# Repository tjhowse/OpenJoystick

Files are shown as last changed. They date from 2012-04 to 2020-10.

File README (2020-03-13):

OpenJoystick

OpenJoystick is a project developing a 3D-printable joystick and throttle for use with flight simulators. The design is centered around making the joystick cheap, easy to assemble and simple to customise. Where-ever possible, commonly available and inexpensive components are used where 3D printed parts would be unsuitable, such as switches, bearings and sensors. The designs of the components are parametric. This means they can be simply modified in a text editor in order to create customised joysticks for different aircraft, left-handed people, or people with limited mobility. The deflection of the joystick is measured using a tri-axis hall effect sensor. This yields great accuracy, reliability and long life, due to non-contact sensing. The 3D models and circuitry used in OpenJoystick are open source under the Gnu Public License. Anyone can visit openjoystick.org download the source code and start hacking.

http://www.youtube.com/watch?v=GIY6-3KwIS8&feature=bf_prev&list=PLC66292176B625E2A&lf=plpp_video

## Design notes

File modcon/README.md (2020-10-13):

# Modular Control Panel

This is a project to create a modular control panel for controlling flight simulators and
games on a computer.

Each module contains a microcontroller that interfaces to the inputs on that module and can
relay the states of those inputs to an adjacent module. A module can be fitted with a USB
port to interface to a PC via a standard HID joystick interface. The input devices can be
joysticks, buttons, switches, sliders, knobs or anything else that can be connected to an
arduino-style microcontroller.

https://www.youtube.com/watch?v=Ra9WzwZtf44

The goal is to enable non- or semi-technical people to build custom computer peripherals
to suit how they want to interact with their favourite game or simulator. The PC interface
is via standard USB HID joystick device, so should work with a wide range of software and
platforms (Windows, OSX, Linux, consoles...?).

## This sounds great! I want one!

This project aims to produce the CAD files, circuit board designs and firmware to support
people building their own modular control panels. Further down the road there may be a
small-scale store selling kits, but that's a fair way away.

This is definitely a do-it-yourself kind of project. It might seem like this would
be impossible for a beginner to build, but it may be simpler than you imagine. Learning
a few new skills and building something that is unique to you can feel very rewarding.
Don't be intimidated!

The main things you'll need are:

### The boxes/lids

These are 3d printed. If you don't have a 3d printer of your own there are online services
that you use to print and ship components to you. Alternatively ask a friend with a 3d
printer, or visit your local makerspace/hackerspace/library. They're more common than you
might think.

### The PCBs

The Printed Circuit Board (PCB) is designed such that it can be ordered from JLC PCB
inexpensively and arrive in a nearly-ready-to-use form. Any components that JLC can't
populate on the board are easy to solder by hand.

### Input devices

Switches, buttons, joysticks, et cetera. These are readily available from your online
retailer of choice. The bill of materials (BoM) will provide model numbers and links
for where you could buy them.

### Soldering iron and solder

A cheap electrical soldering iron and some flux-core solder is all you will need. Don't
be scared! It's not as hard as you might think.

### Bits and bobs

The bill of materials (BoM) will list some inexpensive wires, plugs and header strips
you'll need to assemble your controller modules.

## Fabrication notes

### Drilling large holes in the lid

If you need to drill a 40mm hole to mount a three-axis joystick module, like [this one](https://www.aliexpress.com/item/32808586573.html)
be very careful not to overshoot and break the part. I used a 45mm holesaw and snapped the lid in half
as I broke through the other side. If possible I suggest printing the lid with the hole already in place,
or being very careful when drilling.

## FAQ

### I would like outputs like displays and lights too!

That would be be neat. However I'm not aware of a standard way of getting that information
out of a simulator. There are plenty of examples of custom integrations with specific software,
but I'm not aware of any equivalent to a USB HID joystick input, but for outputs in terms of
near-universal support.

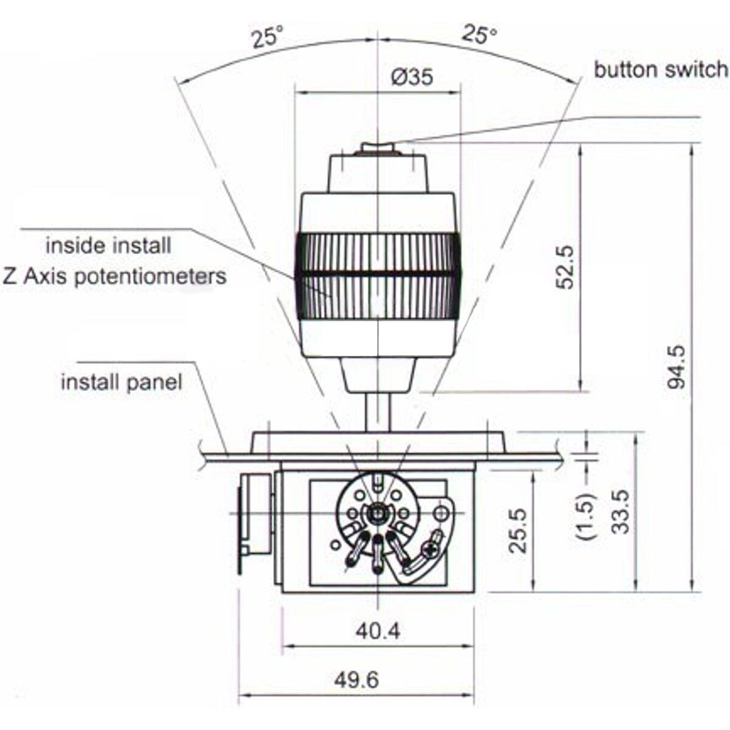
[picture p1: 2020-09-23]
modcon/images/joystick_module_dimensions.jpg

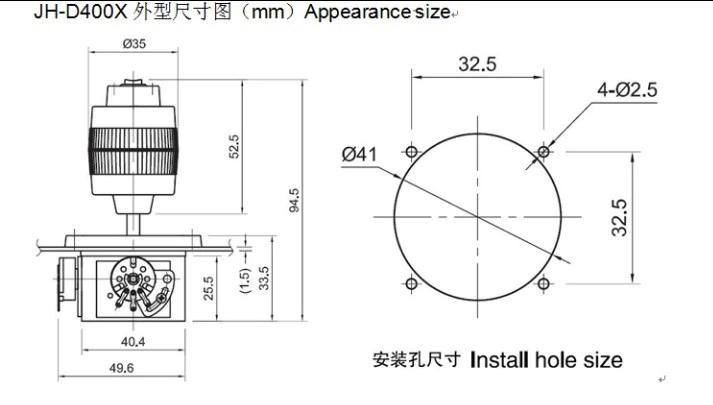
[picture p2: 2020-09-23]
modcon/images/HTB1k1w9kmYH8KJjSspdq6ARgVXaa.webp

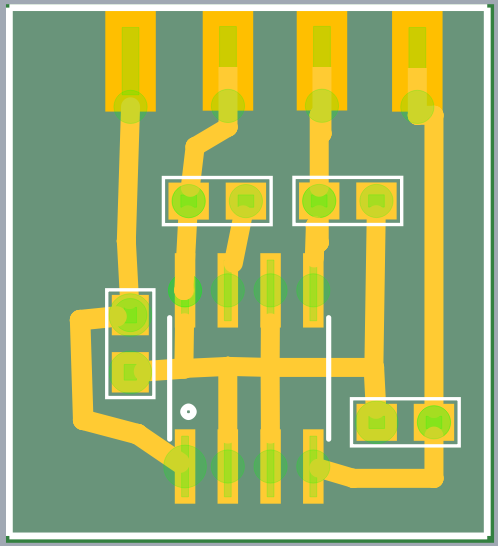
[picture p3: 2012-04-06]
pcb/hall.png

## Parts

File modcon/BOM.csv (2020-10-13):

description | partno | url
Joystick | HW0000997 | https://www.aliexpress.com/item/32808586573.html

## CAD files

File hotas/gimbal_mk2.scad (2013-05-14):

/*
	OpenJoystick - A project creating affordable, open source, 3D-printable custom flight-sim joysticks for everyone
	Copyright (C) 2012 Travis John Howse

	This program is free software: you can redistribute it and/or modify
	it under the terms of the GNU General Public License as published by
	the Free Software Foundation, either version 3 of the License, or
	(at your option) any later version.

	This program is distributed in the hope that it will be useful,
	but WITHOUT ANY WARRANTY; without even the implied warranty of
	MERCHANTABILITY or FITNESS FOR A PARTICULAR PURPOSE.  See the
	GNU General Public License for more details.

	You should have received a copy of the GNU General Public License
	along with this program.  If not, see <http://www.gnu.org/licenses/>.
*/

include <joystick_defines.scad>
use <joystick_handle.scad>

wall_thickness = 2;
m8_bolt_clearance = 1.1;
m8_bolt_head_z = 6.25*m8_bolt_clearance;
m8_bolt_head_min_r = 12.74/2*m8_bolt_clearance;
m8_bolt_head_max_r = 14.55/2*m8_bolt_clearance;

// These come from experimentally-discovered determined values for good springyness
// using 1.5mm spring steel piano wire.
outer_spring_pegs = 50; // Try increasing this.
inner_spring_pegs = 10;

spring_peg_r = 1.5;

bearing_outside_dia = 22*1.02;

y_clearance = 3; // Two washers' worth
anchor_clearance = 3;
z_clearance = 2;
z_extra_bolt_clearance = 1;

y_extra_sleeve_clearance = 2;

y_pegs_offset = bearing_inside_dia/2 + (bearing_inside_dia/2+bearing_inside_dia/2)/2-spring_peg_r;

//spring_z_offset = 2;
spring_z_offset = 2*spring_peg_r;
//spring_z_offset = 0;
spring_peg_sleeve_y = y_pegs_offset-spring_peg_r-(spring_z_offset-2*spring_peg_r);
spring_peg_sleeve_x = y_pegs_offset-spring_peg_r-(spring_z_offset-2*spring_peg_r);

spring_wire_r = 1.5/2;

y_total_z = bearing_thickness*2;	
// y_total_y = outer_spring_pegs+spring_peg_sleeve_y*2+spring_wire_r*2+y_extra_sleeve_clearance;
y_total_y = outer_spring_pegs+spring_peg_sleeve_y*2+y_extra_sleeve_clearance;
y_total_x = (m8_bolt_head_min_r+wall_thickness)*2;

magnet_d = 10*1.1;
magnet_z = 5;

anchor_base_thickness = 2*wall_thickness;
anchor_base_extra_height = 15;
anchor_total_z = bearing_thickness*2;

stem_socket_depth = 10;

module m8_bolt(length,slothead,slotshaft)
{
	rotate([0,0,90]) union()
	{
		translate([0,0,zff]) cylinder(r=m8_bolt_head_max_r,h=m8_bolt_head_z,$fn=6);
		translate([0,0,m8_bolt_head_z]) cylinder(r=bearing_inside_dia/2,h=length);
		if (slothead == 1)
		{
			translate([0,-m8_bolt_head_min_r,0]) cube([m8_bolt_head_min_r*2,m8_bolt_head_min_r*2,m8_bolt_head_z]);
			// translate([0,-bearing_inside_dia/2,m8_bolt_head_z]) cube([m8_bolt_head_min_r*2,bearing_inside_dia,length]);
		}
		if (slotshaft == 1)
		{
			// translate([0,-m8_bolt_head_min_r,0]) cube([m8_bolt_head_min_r*2,m8_bolt_head_min_r*2,m8_bolt_head_z]);
			translate([0,-bearing_inside_dia/2,m8_bolt_head_z]) cube([m8_bolt_head_min_r*2,bearing_inside_dia,length]);
		}
		
	}
}

module y_axis()
{	
	edge_chord = 2*sqrt(pow((bearing_outside_dia+wall_thickness*2)/2,2)-pow(y_total_x/2,2));
	
	difference()
	{
		union()
		{
			bearing_clamp();
			cube([y_total_x,y_total_y,y_total_z],true);
			/*translate([y_pegs_offset,-outer_spring_pegs/2,-y_total_z/2]) cylinder(r=spring_peg_r+wall_thickness,h=y_total_z);
			rotate([0,0,180]) translate([-y_pegs_offset,-outer_spring_pegs/2,-y_total_z/2]) cylinder(r=spring_peg_r+wall_thickness,h=y_total_z);
			translate([-y_pegs_offset,-outer_spring_pegs/2,-y_total_z/2]) cylinder(r=spring_peg_r+wall_thickness,h=y_total_z);
			rotate([0,0,180]) translate([y_pegs_offset,-outer_spring_pegs/2,-y_total_z/2]) cylinder(r=spring_peg_r+wall_thickness,h=y_total_z);*/
		}
				
		translate([0,0,-y_total_z/2])cylinder(r=bearing_outside_dia/2,h=y_total_z);

		translate([0,-bearing_outside_dia/2-wall_thickness,0]) rotate([90,0,0]) m8_bolt(100,1,0);
		rotate([0,0,180]) translate([0,-bearing_outside_dia/2-wall_thickness,0]) rotate([90,0,0]) m8_bolt(100,1,0);
		
		// Spring pegs * 2
		translate([y_pegs_offset,-outer_spring_pegs/2,-y_total_z/2]) cylinder(r=spring_peg_r,h=y_total_z);
		rotate([0,0,180]) translate([-y_pegs_offset,-outer_spring_pegs/2,-y_total_z/2]) cylinder(r=spring_peg_r,h=y_total_z);
		translate([-y_pegs_offset,-outer_spring_pegs/2,-y_total_z/2]) cylinder(r=spring_peg_r,h=y_total_z);
		rotate([0,0,180]) translate([y_pegs_offset,-outer_spring_pegs/2,-y_total_z/2]) cylinder(r=spring_peg_r,h=y_total_z);
		
	}
	
	
}

module x_axis()
{	
	//stem_socket_depth = spring_peg_r*2+wall_thickness;
	
	
	x_hole_x = y_total_z+ y_clearance;
	x_hole_y = bearing_outside_dia+wall_thickness*3 +spring_peg_r*2+z_clearance+z_extra_bolt_clearance;
	//x_total_z = 15;
	x_total_z = m8_bolt_head_min_r*2+spring_peg_r*4+wall_thickness/2;
	
	x_total_x = x_hole_x + wall_thickness*3;
	x_total_y = x_hole_y + wall_thickness*3+stem_socket_depth;
		
	nut_countersink = m8_bolt_head_z;
	difference()
	{
		union()
			{
			difference()
			{
				translate([0,(wall_thickness +spring_peg_r*2+z_extra_bolt_clearance)/2+stem_socket_depth/2,0]) difference()
				{
					cube([x_total_x,x_total_y,x_total_z],true);
					translate([0,-stem_socket_depth/2,0]) cube([x_hole_x,x_hole_y,x_total_z],true);
				}
				
				rotate([0,90,0]) translate([0,0,-50]) cylinder(r=(bearing_inside_dia*1.1)/2,h=100);
			}
			
			translate([0,(wall_thickness +spring_peg_r*2+z_extra_bolt_clearance)/2-x_total_y/2+stem_socket_depth/2,0]) rotate([90,0,0]) difference()
			{
				cylinder(r=magnet_d/2+wall_thickness,h=wall_thickness);
				cylinder(r=magnet_d/2,h=wall_thickness);
			}
			//translate([x_total_x/2,-(m8_bolt_head_max_r*2+wall_thickness)/2,-x_total_z/2]) difference ()
			translate([zff,0,0]) rotate([0,90,0]) difference ()
			{
				translate([0,0,x_total_x/2+nut_countersink/2]) cube([x_total_z,(m8_bolt_head_max_r)*2, nut_countersink],center=true);
				rotate([0,0,30]) cylinder(r=m8_bolt_head_max_r,h=100,$fn=6);
			}
		}
		rotate([0,90,0])
		{
			translate([m8_bolt_head_min_r+spring_peg_r,0,0]) cylinder(r=spring_peg_r,h=100,$fn=10);
			translate([-m8_bolt_head_min_r-spring_peg_r,,0]) cylinder(r=spring_peg_r,h=100,$fn=10);			
		}
		
		translate([0,x_total_y/2+(wall_thickness +spring_peg_r*2+z_extra_bolt_clearance)/2-stem_socket_depth/2,0]) rotate([-90,0,0]) cylinder(r=shaft_dia/2,h=100);
		translate([0,x_total_y/2+(wall_thickness +spring_peg_r*2+z_extra_bolt_clearance)/2,-50]) cylinder(r=spring_peg_r,h=100);
		
	}
}

module bearing_clamp()
{
	translate([0,0,bearing_thickness/2]) single_bearing_clamp();
	translate([0,0,-bearing_thickness/2]) single_bearing_clamp();
}

module single_bearing_clamp()
{
	gap = 3;
	clamp_bolt_r = spring_peg_r;

	difference()
	{
		union()
		{
			translate([0,0,-bearing_thickness/2]) cylinder(r=bearing_outside_dia/2+wall_thickness,h=bearing_thickness);
			translate([bearing_outside_dia/2-wall_thickness,0,0]) cube([wall_thickness*2+clamp_bolt_r*2+bearing_outside_dia/2, wall_thickness*3+gap,bearing_thickness],true);
		}
		translate([0,0,-bearing_thickness/2]) cylinder(r=bearing_outside_dia/2,h=bearing_thickness);
		translate([bearing_outside_dia/2-wall_thickness,0,0]) cube([wall_thickness*2+clamp_bolt_r*2+bearing_outside_dia/2, gap,bearing_thickness],true);
		
		translate([bearing_outside_dia/2+wall_thickness*2,wall_thickness/2,0]) rotate([90,0,0]) translate([0,0,-(wall_thickness*2+gap)/2]) cylinder(r=clamp_bolt_r,h=wall_thickness*3+gap);
	}
}

module spring_peg_sleeve()
{
	spring_peg_sleeve_z = m8_bolt_head_z+wall_thickness*1.5+y_clearance/2+spring_wire_r*2;
	difference()
	{
		union()
		{
			cylinder(r=spring_peg_sleeve_y+spring_wire_r,h=spring_peg_sleeve_z-spring_wire_r*2);
			translate([0,0,spring_peg_sleeve_z-spring_wire_r*2]) cylinder(r1=spring_peg_sleeve_y+spring_wire_r,r2=spring_peg_sleeve_y,h=spring_wire_r);
			translate([0,0,spring_peg_sleeve_z-spring_wire_r]) cylinder(r1=spring_peg_sleeve_y,r2=spring_peg_sleeve_y+spring_wire_r,h=spring_wire_r);
			
		}
		cylinder(r=spring_peg_r,h=spring_peg_sleeve_z);
	}		
}
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

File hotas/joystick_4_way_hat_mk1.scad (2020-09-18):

/*
	OpenJoystick - A project creating affordable, open source, 3D-printable custom flight-sim joysticks for everyone
	Copyright (C) 2012 Travis John Howse

	This program is free software: you can redistribute it and/or modify
	it under the terms of the GNU General Public License as published by
	the Free Software Foundation, either version 3 of the License, or
	(at your option) any later version.

	This program is distributed in the hope that it will be useful,
	but WITHOUT ANY WARRANTY; without even the implied warranty of
	MERCHANTABILITY or FITNESS FOR A PARTICULAR PURPOSE.  See the
	GNU General Public License for more details.

	You should have received a copy of the GNU General Public License
	along with this program.  If not, see <http://www.gnu.org/licenses/>.
*/

include <joystick_defines.scad>

// See joystick_defines for most of the guts.

//translate([0,0,10])
//	4_way_hat_washer();
//translate([0,0,13])
//	switch_hat_saddle();
//  switch_hat_hanoi();
//pb(1);

module hat_base(numDirs)
{
	difference()
	{
		cylinder(r=(4_way_hat_base_dia/2), h=4_way_hat_base_z, $fn=circle_faces);
		
		translate([0,pb_total_z+(4_way_hat_base_screw_dia/2),4_way_hat_base_z-pb_xy/2+zff])
			rotate([90,0,0])
				pb(1.02,0);
		translate([0,-pb_total_z-(4_way_hat_base_screw_dia/2),4_way_hat_base_z-pb_xy/2+zff])
			rotate([-90,180,0])
				pb(1.02,0);
		if (numDirs==4)
		{
			translate([pb_total_z+(4_way_hat_base_screw_dia/2),0,4_way_hat_base_z-pb_xy/2+zff])
				rotate([90,0,-90])
					pb(1.02,0);
			translate([-pb_total_z-(4_way_hat_base_screw_dia/2),0,4_way_hat_base_z-pb_xy/2+zff])
				rotate([-90,180,-90])
					pb(1.02,0);
//			// Now chop the bit out of the middle
			translate([0,0,4_way_hat_base_base_z+zff])
				//cube([4_way_hat_base_screw_dia+2*pb_btn_z+zff,4_way_hat_base_screw_dia+2*pb_btn_z+zff,10],center=true);
                cylinder(r=sqrt(pow((pb_btn_dia/2),2) + pow((4_way_hat_base_screw_dia/2+pb_btn_z),2)),h=10,$fn=circle_faces);
		} else	{
			// Now chop the bit out of the middle
			translate([0,0,4_way_hat_base_base_z+5])
				cube([4_way_hat_base_screw_dia,4_way_hat_base_screw_dia+2*pb_btn_z+zff,10],center=true);
		}

		// Now chop the bit out of the middle
		/*translate([0,0,4_way_hat_base_base_z+5])
			cube([pb_xy+zff,pb_xy+zff,10],center=true);*/

		// Screw
		translate([0,0,-1])
            union()
            {
                rotate([0,5,0]) cylinder(r=4_way_hat_base_screw_dia/2, h=4_way_hat_base_z*1, $fn=circle_faces);
                rotate([0,-5,0]) cylinder(r=4_way_hat_base_screw_dia/2, h=4_way_hat_base_z*1, $fn=circle_faces);
                rotate([5,0,0]) cylinder(r=4_way_hat_base_screw_dia/2, h=4_way_hat_base_z*1, $fn=circle_faces);
                rotate([-5,0,0]) cylinder(r=4_way_hat_base_screw_dia/2, h=4_way_hat_base_z*1, $fn=circle_faces);
                cylinder(r=4_way_hat_base_screw_dia/2, h=4_way_hat_base_z*1, $fn=circle_faces);
            }
	}		
}

module hat_voids(numDirs)
{
	difference()
	{
		cylinder(r=4_way_hat_base_dia/2, h=4_way_hat_base_z);		
		hat_base(numDirs);
	}
}

module switch_hat_saddle()
{
	step_size = 2; // Won't really work for anything other than 2, sorry.
	num_steps = 4_way_hat_base_dia / step_size;
	switch_hat_saddle_base_depth = 4_way_hat_peg_stem_hole_z;


	union()
	{
		translate([0,0,switch_hat_saddle_base_depth])
			intersection()
			{
				cylinder(r = (4_way_hat_base_dia/2), h = 10, $fn=circle_faces);
				for (n = [0:num_steps])
				{
					translate([-(4_way_hat_base_dia/2)+n*step_size+0.25*step_size,0,0])
						cube([step_size, 4_way_hat_base_dia, abs((num_steps/2)-n)*1.5],center=true);
				}
			}
		difference()
		{
			cylinder(r = (4_way_hat_base_dia/2), h = switch_hat_saddle_base_depth, $fn=circle_faces);
			translate([0,0,-zff])
				#cylinder(r=(4_way_hat_base_screw_dia/2), h =switch_hat_saddle_base_depth, $fn=circle_faces);
		}
	}
}

module switch_hat_hanoi()
{
	
	difference()
	{
		union()
		{
			cylinder(r = (4_way_hat_base_dia/2), h = 2, $fn=circle_faces);
			translate([0,0,2])
			{
				for (n = [1:8])
				{
					cylinder(r = (4_way_hat_base_dia/2 - (n-1)), h = n*0.7, $fn=circle_faces);
				}
			}
		}
		translate([0,0,-zff])
			cylinder(r=(4_way_hat_base_screw_dia/2), h = 4_way_hat_peg_stem_hole_z, $fn=circle_faces);
	}	
}

module 4_way_hat_washer()
{
	difference()
	{
		cylinder(r=(4_way_hat_base_dia/2), h = 1, $fn=circle_faces);
		translate([0,0,-zff])
			cylinder(r=(4_way_hat_base_screw_dia/2), h = 1+2*zff, $fn=circle_faces);
	}
}

module hat_stem(height)
{
	bolt(8.5/2, 1.5, 4.5/2, height,0);
}
	
//hat_stem(11); // Face hats
hat_stem(23); // CMS
//switch_hat_hanoi();

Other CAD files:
hotas/joystick_assembled.scad
hotas/joystick_centring_plate_mk1.scad
from_old_openscad_folder/joystick_4_way_hat_mk1.scad
from_old_openscad_folder/joystick_assembled.scad
from_old_openscad_folder/joystick_defines.scad
from_old_openscad_folder/joystick_gimbal_core_mk1.scad
from_old_openscad_folder/joystick_gimbal_frame_mk1.scad
hotas/joystick_defines.scad
hotas/joystick_gimbal.scad
hotas/joystick_gimbal_core_mk1.scad
hotas/joystick_gimbal_frame_mk1.scad
hotas/joystick_handle.scad
hotas/joystick_head.scad
hotas/joystick_head_precompile.scad
hotas/throttle.scad
modcon/modcon.scad

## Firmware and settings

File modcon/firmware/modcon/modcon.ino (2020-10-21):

// I2C library
#include <Wire.h>
// USB HID library
#include "HID-Project.h"

// Settings library
// #include "settings.h"

#include "host.h"
#include "guest.h"

void update_inputs_local() {
    // This polls the local GPIO for the states of the inputs attached to this module.
    uint8_t a_count = 0;
    uint8_t d_count = 0;
    // local_digital_values = 0x0000;
    for (i = 0; i < INPUT_PIN_COUNT; i++) {
        if (settings.analog_input_mask & (0x0001<<i)) {
            // Read an analogue value
            local_analog_values[a_count++] = analogRead(input_pins[i]);
            if (is_host) {
                handle_analog_value(local_analog_values[a_count-1]);
            }
        } else if (settings.digital_input_mask & (0x0001<<i)) {
            // Read a digital value
            if (digitalRead(input_pins[i])) {
                bitSet(local_digital_values, d_count++);
            } else {
                bitClear(local_digital_values, d_count++);
            }
            if (is_host) {
                handle_digital_value(bitRead(local_digital_values, d_count-1));
            }
        }
    }
}

void update_mode() {
    bool mode_btn_state = digitalRead(PIN_BTN_MODE);
    if (!mode_btn_state && mode_btn_prev) {
        // Falling edge
        if (mode == MODE_LEARN) {
            teardown_learn_mode();
        } else {
            setup_learn_mode();
        }
    }
    mode_btn_prev = mode_btn_state;
}

void learn_inputs() {
    uint16_t temp;
    for (i = 0; i < INPUT_PIN_COUNT; i++) {
        temp = analogRead(input_pins[i]);
        if ((temp > (ANALOG_PIN_MIN + ANALOG_DETECTION_BOUNDARY)) &&
            (temp < (ANALOG_PIN_MAX - ANALOG_DETECTION_BOUNDARY))) {
            // This pin is almost definitely either floating or analogue.
            // Set its bit in settings.analog_input_mask.
            bitSet(settings.analog_input_mask, i);
            bitClear(settings.digital_input_mask, i);
        }
        if (!bitRead(settings.analog_input_mask,i) &&
            (((local_analog_values[i] > (ANALOG_PIN_MAX - ANALOG_DETECTION_BOUNDARY)) &&
             (                  temp < (ANALOG_PIN_MIN + ANALOG_DETECTION_BOUNDARY))) ||
            ((                  temp > (ANALOG_PIN_MAX - ANALOG_DETECTION_BOUNDARY)) &&
             (local_analog_values[i] < (ANALOG_PIN_MIN + ANALOG_DETECTION_BOUNDARY))))) {
            // Oof.
            // This detects whether an input that was previously close to max has gone close to min
            // or it was close to min and has gone to max.
            bitSet(settings.digital_input_mask, i);
        }
        local_analog_values[i] = temp;
    }
}

void setup_learn_mode() {
    mode = MODE_LEARN;
    settings.analog_input_mask = 0x0000;
    settings.digital_input_mask = 0x0000;
    settings.local_a_input_count = 0;
    settings.local_d_input_count = 0;

    for (i = 0; i < INPUT_PIN_COUNT; i++) {
        local_analog_values[i] = analogRead(input_pins[i]);
    }
    if (is_host) {
        setup_learn_mode_host();
    } else {
        setup_learn_mode_guest();
    }
}

void teardown_learn_mode() {
    mode = MODE_NORMAL;
    Serial.println("Leaving learn mode");
    for (i = 0; i < INPUT_PIN_COUNT; i++) {
        if (bitRead(settings.analog_input_mask, i)) {
            settings.local_a_input_count++;
        }
        if (bitRead(settings.digital_input_mask, i)) {
            settings.local_d_input_count++;
        }
    }
    Serial.print("A: ");
    Serial.println(settings.analog_input_mask, BIN);
    Serial.print("D: ");
    Serial.println(settings.digital_input_mask, BIN);
    Serial.println();
    Serial.print("Total analogue axes: ");
    Serial.println(settings.local_a_input_count);
    Serial.print("Total digital axes: ");
    Serial.println(settings.local_d_input_count);
    settings.save();
}

void setup_pins() {
    pinMode(PIN_BTN_MODE, INPUT_PULLUP);
    pinMode(PIN_HOST, INPUT_PULLUP);
    pinMode(PIN_RXLED, OUTPUT);
    for (i = 0; i < INPUT_PIN_COUNT; i++) {
        pinMode(input_pins[i], INPUT_PULLUP);
    }
}

bool check_if_host() {
    // This function returns true if this module is the host, otherwise false.
    // delay(STARTUP_DELAY_MS)
    // // Note this must be read after a delay, it's not accurate on boot.
    // return UDADDR & _BV(ADDEN);
    // For testing I'm using a GPIO pin to set a module to guest/host rather
    // than auto-detecting based on USB state.
    return digitalRead(PIN_HOST);
}

void setup() {
    setup_pins();
    is_host = check_if_host();
    mode = MODE_NORMAL;
    mode_btn_prev = 1;
    settings.load();
    Serial.begin(115200);
    delay(1000);
    if (is_host) {
        setup_host();
    } else {
        setup_guest();
    }
}

void loop_normal() {
    if (is_host) {
        loop_host();
    } else {
        loop_guest();
    }
}

void loop_learn() {
    learn_inputs();
    if (is_host) {
        loop_learn_host();
    } else {
        loop_learn_guest();
    }
}

void loop_leds() {
    if (mode == MODE_NORMAL) {
    // if (is_host) {
        digitalWrite(PIN_RXLED, LOW);
    } else {
        if ((millis() - last_blink_ms) > (is_host ? HOST_LEARN_MODE_BLINK_INTERVAL_MS : GUEST_LEARN_MODE_BLINK_INTERVAL_MS)) {
            blink_prev = !blink_prev;
            last_blink_ms = millis();
            if (blink_prev) {
                digitalWrite(PIN_RXLED, LOW);
            } else {
                digitalWrite(PIN_RXLED, HIGH);
            }
        }
    }
}

void loop() {
    update_mode();
    loop_leds();
    if (mode == MODE_NORMAL) {
        loop_normal();
    } else if (mode == MODE_LEARN) {
        loop_learn();
    }
    delay(10);
}

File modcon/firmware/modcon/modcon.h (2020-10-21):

#include <EEPROM.h>

#define MODE_NORMAL 0
#define MODE_LEARN 1

// Wait this many MS before determining whether we're a guest or host module.
#define STARTUP_DELAY_MS 1000
#define GUEST_LEARN_MODE_BLINK_INTERVAL_MS 100
#define HOST_LEARN_MODE_BLINK_INTERVAL_MS 1000

#define PIN_BTN_MODE 16
#define PIN_RXLED 17
#define PIN_HOST 7

#define LEARNING_I2C_ADDRESS 0x08
#define DEFAULT_I2C_ADDRESS 0x70

#define I2C_ADDRESS_ALLOCATION_START 0x10

#define INPUT_PIN_COUNT 8

#define MODE_DEBOUNCE_MS 500

// If an analog input reads further than this value from min or max
// then it's deemed to be an analogue input.
#define ANALOG_DETECTION_BOUNDARY 100
#define ANALOG_PIN_MAX 1023
#define ANALOG_PIN_MIN 0

bool is_host = false;
volatile uint8_t mode = MODE_NORMAL;

// For now, only use analogue inputs. If this changes be sure to also change INPUT_PIN_COUNT
// Leaving out A10 due to weird internal pull-up problems
uint8_t input_pins[] = {A0, A1, A2, A3, A6, A7, A8, A9};
uint8_t i, j;
// The ADCs on the atmel32u4 are 10-bit, so allocate 16 bits per input.
// If this ever gets bigger than 32B we can't put it through I2C in one message.
uint16_t local_analog_values[INPUT_PIN_COUNT];
uint16_t local_digital_values;

uint32_t last_blink_ms = 0;
bool blink_prev;
bool mode_btn_prev;

void update_inputs_local();
void handle_analog_value(uint16_t);
void handle_digital_value(bool);

// These are the addresses in EEPROM for each setting.
// The SETTINGS_SCHEMA is used to avoid
#define SETTINGS_SETTINGS_SCHEMA_A 0
#define SETTINGS_SCHEMA 0x5A
#define SETTINGS_ADDR_A 1
#define SETTINGS_GUEST_COUNT_A 2
#define SETTINGS_ANALOG_INPUT_MASK_A 3 // and 4.
#define SETTINGS_DIGITAL_INPUT_MASK_A 5 // and 6.

class Settings {
    public:
        // A guest module's I2C address. 0x00 on a host module.
        uint8_t addr;
        // How many guest modules do we know about?
        uint8_t guest_count;
        // A bitmask that stores whether a pin is analogue (0) or digital (1)
        uint16_t analog_input_mask;
        uint16_t digital_input_mask;
        uint8_t local_a_input_count;
        uint8_t local_d_input_count;

    void defaults() {
        addr = DEFAULT_I2C_ADDRESS;
        guest_count = 0;
        analog_input_mask = 0;
        digital_input_mask = 0;
    }

    bool load() {
        // Load the settings from EEPROM into this class.
        if (SETTINGS_SCHEMA != EEPROM.read(SETTINGS_SETTINGS_SCHEMA_A)) {
            // We don't recognise this EEPROM SETTINGS_SCHEMA. Load defaults and save them.
            defaults();
            save();
            return false;
        }
        addr = EEPROM.read(SETTINGS_ADDR_A);
        guest_count = EEPROM.read(SETTINGS_GUEST_COUNT_A);
        analog_input_mask = EEPROM.read(SETTINGS_ANALOG_INPUT_MASK_A);
        analog_input_mask |= EEPROM.read(SETTINGS_ANALOG_INPUT_MASK_A+1)<<8;
        digital_input_mask = EEPROM.read(SETTINGS_DIGITAL_INPUT_MASK_A);
        digital_input_mask |= EEPROM.read(SETTINGS_DIGITAL_INPUT_MASK_A+1)<<8;
        local_a_input_count = 0;
        local_d_input_count = 0;
        for (int i = 0; i < INPUT_PIN_COUNT; i++) {
            if (bitRead(analog_input_mask, i)) {
                local_a_input_count++;
            }
            if (bitRead(digital_input_mask, i)) {
                local_d_input_count++;
            }
        }
        return true;
    }
    void save() {
        // Save the settings from this class into EEPROM.
        EEPROM.write(SETTINGS_ADDR_A, addr);
        EEPROM.write(SETTINGS_GUEST_COUNT_A, guest_count);
        EEPROM.write(SETTINGS_ANALOG_INPUT_MASK_A, lowByte(analog_input_mask));
        EEPROM.write(SETTINGS_ANALOG_INPUT_MASK_A+1, highByte(analog_input_mask));
        EEPROM.write(SETTINGS_DIGITAL_INPUT_MASK_A, lowByte(digital_input_mask));
        EEPROM.write(SETTINGS_DIGITAL_INPUT_MASK_A+1, highByte(digital_input_mask));
        EEPROM.write(SETTINGS_SETTINGS_SCHEMA_A, SETTINGS_SCHEMA);
    }
};

Settings settings;

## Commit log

2011-09-12 First commit.
    [joystick_4_way_hat_mk1.scad, joystick_assembled.scad, joystick_centring_plate_mk1.scad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]
2012-03-19 Many changes to pretty much everything.
    Still in the roughing-in phase.
    [joystick_4_way_hat_mk1.scad, joystick_defines.scad, joystick_head.scad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]
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2012-03-21 Further work on the head. Nearing completion.
    [joystick_head.scad, joystick_head_precompile.scad]
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2012-03-21 Fixed formatting
    [joystick_head.scad]
2012-03-22 Added hole for trigger return spring...
    And I added the mode button as well as a channel for its wires.
    [joystick_defines.scad, joystick_head.scad]
2012-03-23 Head pretty much finished. Moving onto handle now.
    [joystick_handle.scad, joystick_head.scad]
2012-03-23 Printing this version of the handle now.
    [joystick_defines.scad, joystick_handle.scad, joystick_head.scad]
2012-03-23 Some changes to the CMS stem.
    This is the version I used in the first youtube video.
    [joystick_defines.scad, joystick_handle.scad]
2012-03-25 Big one! Added split in stick, added CMS bolt...
    Added support to CMS socket and pegs.
    [joystick_4_way_hat_mk1.scad, joystick_defines.scad, joystick_handle.scad]
2012-03-25 Creating button, added link to BoM.
    [joystick_defines.scad, joystick_handle.scad, joystick_head.scad]
2012-03-26 Added a new gimbal design.
    The old one, Mk1, is now useless.
    [joystick_4_way_hat_mk1.scad, joystick_defines.scad, joystick_gimbal.scad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]
2012-03-27 About to try a new coupling in the gimbal.
    I'm going to change the slot system to a slightly different slot system.
    [joystick_gimbal.scad]
2012-03-27 Experiment successful! New gimbal design is great.
    [joystick_gimbal.scad]
2012-03-29 About to pretty radically change the gimbal.
    Hopefully for the better.
    [joystick_defines.scad, joystick_gimbal.scad]
2012-03-29 Looking good post-change.
    Might be about to break something though.
    [joystick_gimbal.scad]
2012-03-29 Enbeefened the support stem and the Y axis screws
    [joystick_gimbal.scad]
2012-03-29 Almost-final version of gimbal. Mk3.
    [joystick_gimbal.scad]
2012-03-31 A few tweaks.
    Mostly fixing minor bugs discovered in assembling the gimbal.
    [joystick_gimbal.scad, joystick_handle.scad, joystick_head.scad]
2012-04-02 Added a washer for accurate spacings.
    [joystick_gimbal.scad]
2012-04-03 About to work on the big button.
    [joystick_gimbal.scad, joystick_head.scad]
2012-04-06 Added PCB file.
    [hall.fzz, joystick_head.scad]
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2012-04-07 Added bolts for holding the head on.
    And added some extra depth for the face-attach bolts to.
    [joystick_defines.scad, joystick_handle.scad, joystick_head.scad]
2012-04-08 Added gimbal assembly alignment jig.
    Helps keep the proper spacing around the joiner stem when tightening the
    bolts holding the Y axis pegs. Remove after assembling the gimbal.
    [joystick_gimbal.scad, joystick_head.scad]
2012-04-16 Fillet and mounting holes to gimbal base.
    [joystick_defines.scad, joystick_gimbal.scad, joystick_head.scad]
2012-04-16 License info, and first pass at magnet holder.
    [joystick_4_way_hat_mk1.scad, joystick_assembled.scad, joystick_centring_plate_mk1.scad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]
2012-04-25 Added lips and screwholes for mounting plates
    These plates will hold the switches and hats on the side and rear of the
    right quadrant of the throttle.
    [joystick_4_way_hat_mk1.scad, joystick_gimbal.scad, joystick_head.scad]
2012-04-25 Added holes for hats and switches throttle end.
    At the present they're two-way hats, but I'm going to replace two of them
    with three-position switches.
    [joystick_head.scad]
2012-04-27 Added the throttle scad.
    I've been commiting without actually having this file in the repo. X-(
    [throttle.scad]
2012-04-27 Added some clearance around the plates.
    Amount of clearance is a variable to help the plates fit properly. Started
    messing around with how to interface switches into the plates.
    [throttle.scad]
2012-04-28 Built, threw out and rebuilt some switches.
    For the throttle endplate.
    [throttle.scad]
2012-04-28 Added guides for throttle end switches.
    Playing with the clearances of the plates a bit more.
    [throttle.scad]
2012-04-30 Backup prior to reworking air brake switch.
    [throttle.scad]
2012-04-30 New, semi-final version of the airbreak switch.
    [throttle.scad]
2012-05-03 Not happy about calibration hat. About to rework.
    [joystick_defines.scad, joystick_gimbal.scad, throttle.scad]
2012-05-03 Calibration hat improving.
    [joystick_defines.scad, joystick_gimbal.scad]
2012-05-04 Chamfered edges of springbars.
    Changed spring offset on gimbal. Added clearance on gimbal pegs.
    [joystick_gimbal.scad]
2012-06-10 Working on "clickable CMS" task.
    [joystick_4_way_hat_mk1.scad, joystick_defines.scad, joystick_gimbal.scad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]
2013-04-26 Begun work on a new gimbal design.
    Not sure if it's the best way to go, but we'll see.
    [gimbal_mk2.scad]
2013-04-27 New, more compact gimbal y.
    [gimbal_mk2.scad]
2013-04-29 X axis done, mostly. Reworking the spring system.
    [gimbal_mk2.scad]
2013-05-04 Failed spring experiment.
    [gimbal_mk2.scad]
2013-05-05 A promising approach to the spring situation.
    [gimbal_mk2.scad]
2013-05-06 Added Y axis anchors and finalised the X spring
    [gimbal_mk2.scad]
2013-05-07 Almost finished gimbal redesign.
    [gimbal_mk2.scad]
2013-05-13 Version from Mk2 video.
    [gimbal_mk2.scad]
2013-05-14 Working towards the rubber band centring.
    [gimbal_mk2.scad]
2020-09-18 Move HOTAS scads into their own directory.
    [gimbal_mk2.scad, joystick_4_way_hat_mk1.scad, joystick_assembled.scad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]
2020-09-18 Start working on the modular controller thing.
    [modcon.scad]
2020-09-18 Working on the lid.
    [modcon.scad]
2020-09-18 Lid mostly done.
    [modcon.scad]
2020-09-18 Start working on the base.
    [modcon.scad]
2020-09-23 Work work.
    [modcon.scad]
2020-09-27 About to work on the locking mechanism.
    [modcon.scad]
2020-09-27 Working on the join_lock
    [modcon.scad]
2020-09-30 Adding the locking mechanism.
    [modcon.scad]
2020-09-30 Working on a new join lock idea
    [modcon.scad]
2020-10-03 More work on join_pin and docs.
    [modcon.scad]
2020-10-03 Trying another clip approach.
    [modcon.scad]
2020-10-03 Try making the spring arms thinner.
    [modcon.scad]
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2020-10-18 Quite broken right now, but moving towards the required structure.
    [modcon.h, modcon.ino]
2020-10-21 Fix some bitwise logic.
    [modcon.ino]
2020-10-21 EEPROM saving works!
    Many other fixes too.
    [modcon.h, modcon.ino]
2020-10-22 Add a new lid variant for six 10 amp switches.
    [modcon.scad]
2021-01-05 Tweak switch layout on 6x2 10A switch plate.
    [modcon.scad]
